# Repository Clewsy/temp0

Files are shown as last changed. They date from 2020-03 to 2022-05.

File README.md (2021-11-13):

# temp0
A temperature/humidity sensor that provides live readings over WiFi and via an oled display.
The device connects to a local network over WiFi and serves the following:
- Pretty html page at root:
	- http://temp0
- Simple text only temperature value at:
	- http://temp0/temperature
	- http://temp0/temp
	- http://temp0/t
- Simple text only humidity value at:
	- http://temp0/humidity
	- http://temp0/humi
	- http://temp0/h

The code was developed using the [PlatformIO][link_web_platformio] extension in [VSCode][link_web_vscode].  The hardware was designed using [KiCAD][link_web_kicad] and fabricated using [JLCPCB][link_web_jlcpcb].

All components are on a custom PCB and inside an enclosure with a transperant lid so as to show off the special-edition [HackADay 10-year anniversary Pro Trinket][link_web_hackaday_pro_trinket]!

More info can be found [here][link_clews_projects_temp0].

## Goals
This project was developed to meet a few goals:
- Create a device for monitoring internal temperature - to be compatible with automation platforms (specifically [Home Assistant][link_web_home_assistant]).
	- Local temperature read-out.
	- Simple web-server for obtaining temperature over WiFi.
	- Simple text-only response when calling a specific url with curl (also over WiFi). 
- Make use of - and potentially showcase - a special [HackADay 10-year anniversary edition Pro-Trinket][link_web_hackaday_pro_trinket] dev board.
- Learn how to use an [esp8266][link_web_esp8266].
- Try out [arduino][link_web_arduino] (instead of directly programming microcontrollers).
	- Try the [arduino IDE][link_web_arduino_ide] and programming via the arduino bootloader.
	- Try using some [C++][link_wiki_c++] for development instead of just [C][link_wiki_c].

## Components
The final system consists of the following components:
- [Pro Trinket 5V][link_repo_data_pro_trinket] (Hackaday 10-Year Anniversary Special-Edition) - Controls the SSD1306 and the HDC1080. Sends temperature/humidity readings over serial to the ESP8266 module.
- [ESP8266][link_repo_data_esp8266] (ESP-01 module) - Acts as a web-server to provide temperature/humidity over WiFi.
- [HDC1080][link_repo_data_hdc1080] module - Temperature/Humidity sensor that communicates over I2C.
- [SSD1306][link_repo_data_ssd1306] OLED module - also communicates over I2C - used as a local display for temperature/humidity readings.
- Miscellaneous components for power conversion (5V->3.3V), filtering, IO pull-ups, etc.

## Repository
This repo contains:
- [data][link_repo_temp0_data] - datasheets I referenced to write relevant code and create custom [KiCAD][link_web_kicad] footprints.
- [images][link_repo_temp0_images] - photos of the final project.
- [temp0_esp8266][link_repo_temp0_esp8266] - code written for the ESP8266/ESP-01 module.
- [temp0_pro_trinket][link_repo_temp0_pro_trinket] - code written for the Pro Trinket module.
- [temp0_schematic][link_repo_temp0_schematic] - [KiCAD][link_web_kicad] files including the schematic and PCB layout.  Library includes some custom parts (ESP-01, Pro-Trinket, HDC1080, OLED).
- [temp0_workspace.code-workspace][link_repo_temp0_workspace] - Workspace structure for VSCode including PlatformIO configurations for working with the ESP8266/ESP-01 and the Pro-Trinket 5V.

## Gallery
### Start-up animation.
Demo of startup

### Cycling through different display modes.
Demo of display modes

### Assembled PCB.
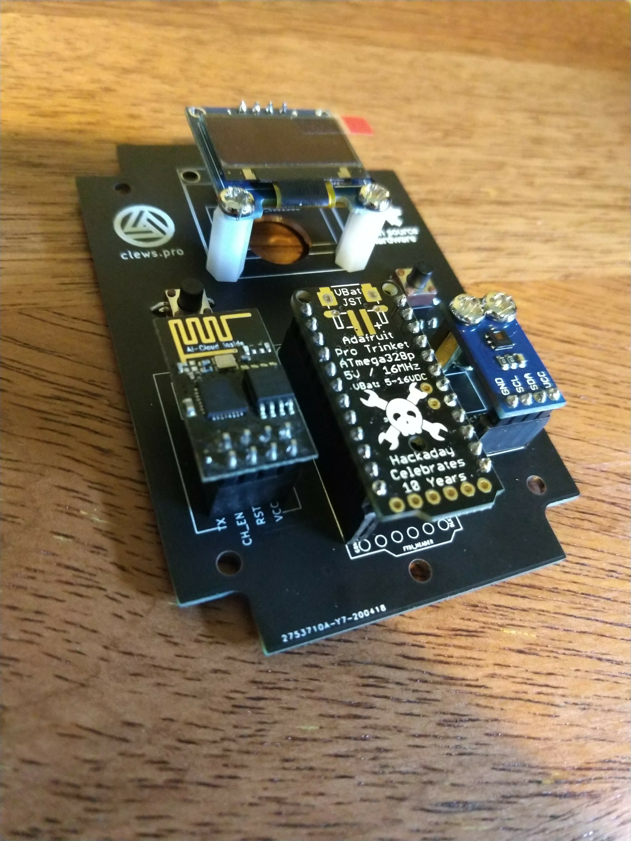
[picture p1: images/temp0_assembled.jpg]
Assembled unit


### In an enclosure.
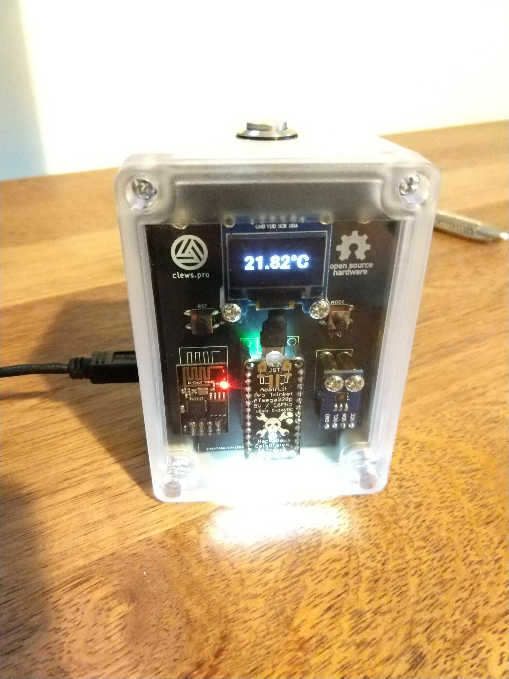
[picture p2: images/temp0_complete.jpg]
Buttoned up


### Web interface.
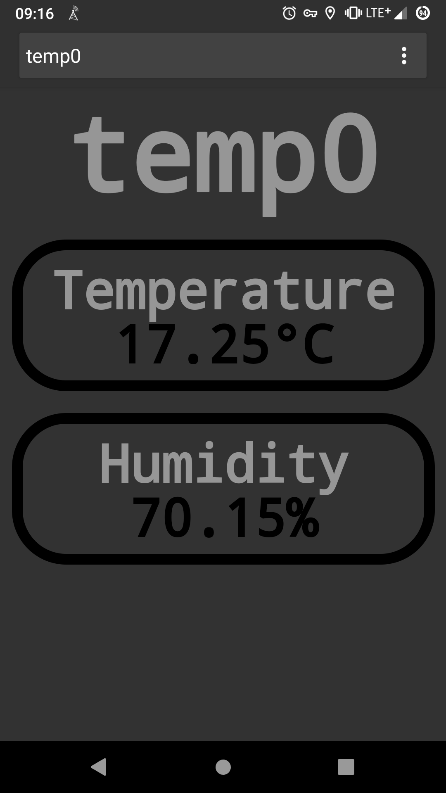
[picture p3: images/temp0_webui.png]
WebUI


[link_clews_projects_temp0]:https://clews.pro/projects/temp0.php

[link_repo_temp0_data]:/data
[link_repo_data_esp8266]:/data/esp8266_pinout.png
[link_repo_data_hdc1080]:/data/hdc1080_i2c_temperature_humidity_sensor.pdf
[link_repo_data_pro_trinket]:/data/pro_trinket_5V_pinout.jpeg
[link_repo_data_ssd1306]:/data/ssd1306_oled_driver.pdf

[link_repo_temp0_esp8266]:/temp0_esp8266
[link_repo_temp0_images]:/images
[link_repo_temp0_pro_trinket]:/temp0_pro_trinket
[link_repo_temp0_schematic]:/temp0_schematic
[link_repo_temp0_workspace]:/temp0_workspace.code-workspace

[link_web_arduino]:https://www.arduino.cc/
[link_web_arduino_ide]:https://www.arduino.cc/en/Main/Software
[link_web_esp8266]:http://esp8266.net/
[link_web_hackaday_pro_trinket]:https://hackaday.com/2014/10/10/10th-anniversary-trinket-pro-now-in-the-hackaday-store/
[link_web_home_assistant]:https://www.home-assistant.io/
[link_web_jlcpcb]:https://jlcpcb.com/
[link_web_kicad]:https://kicad.org/
[link_web_platformio]:https://platformio.org/
[link_web_vscode]:https://code.visualstudio.com/

[link_wiki_c]:https://en.wikipedia.org/wiki/C_(programming_language)
[link_wiki_c++]:https://en.wikipedia.org/wiki/C%2B%2B

[image_temp0_assembled]:/images/temp0_assembled.jpg
[image_temp0_complete]:/images/temp0_complete.jpg
[image_temp0_demo_modes]:/images/temp0_demo_modes.gif
[image_temp0_demo_startup]:/images/temp0_demo_startup.gif
[image_temp0_webui]:/images/temp0_webui.png

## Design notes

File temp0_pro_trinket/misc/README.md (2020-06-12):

# Embedded bitmaps

This directory contains the bitmap images embedded in the pro trinket for displaying on the oled.

The original bitmaps have the suffix *original*.

These original files were manipulated by reversing the order of each 8-bit pixel column, resulting in 8 "rows" flipped vertically.  This manipulation was done to suit an online bitmap-to-char-array convert I used to create the include/ssd1306_bitmaps.h header file which contains these arrays.

The online converter I used is [dot2pic.com][link_web_dot2pic].

Converting images this way allowed me to print them to the OLED with *map_bits* function using the same OLED addressing method as the *clear_screen* function.

[link_web_dot2pic]:http://dot2pic.com/

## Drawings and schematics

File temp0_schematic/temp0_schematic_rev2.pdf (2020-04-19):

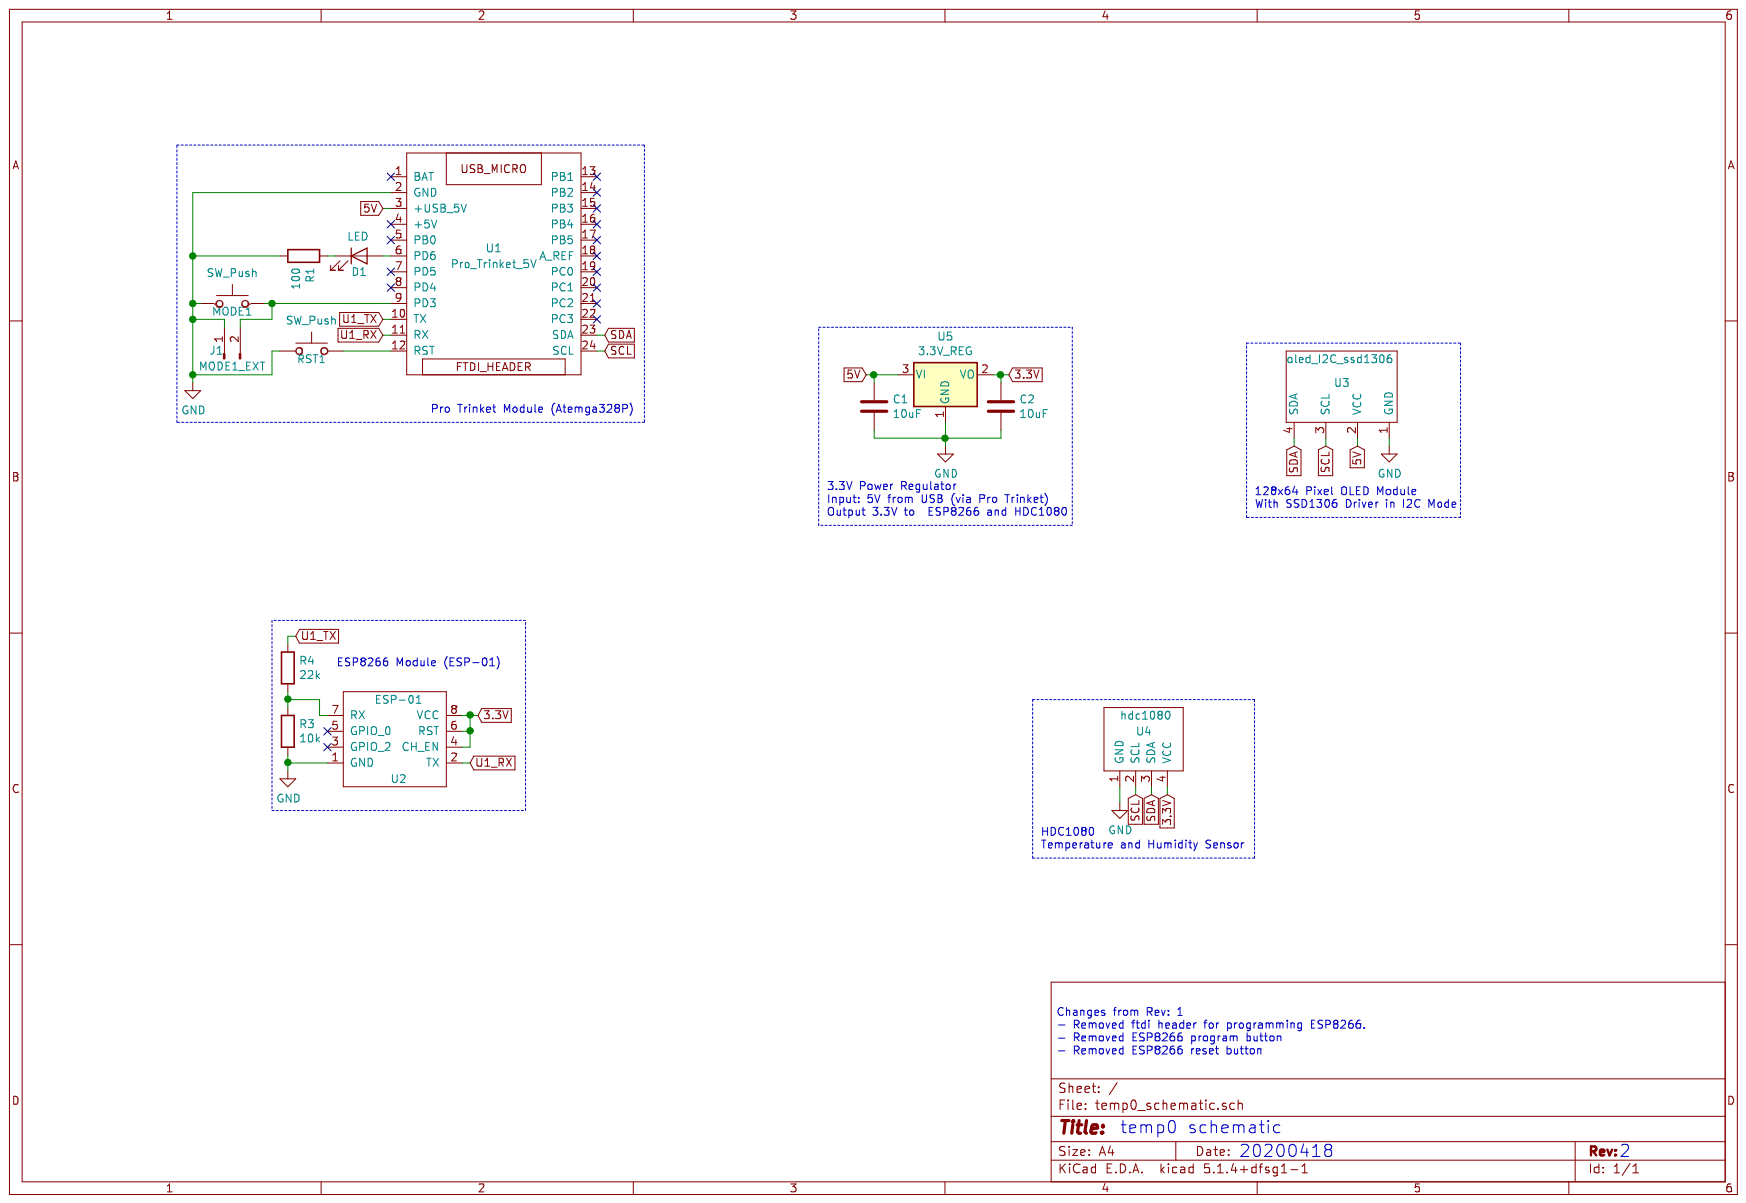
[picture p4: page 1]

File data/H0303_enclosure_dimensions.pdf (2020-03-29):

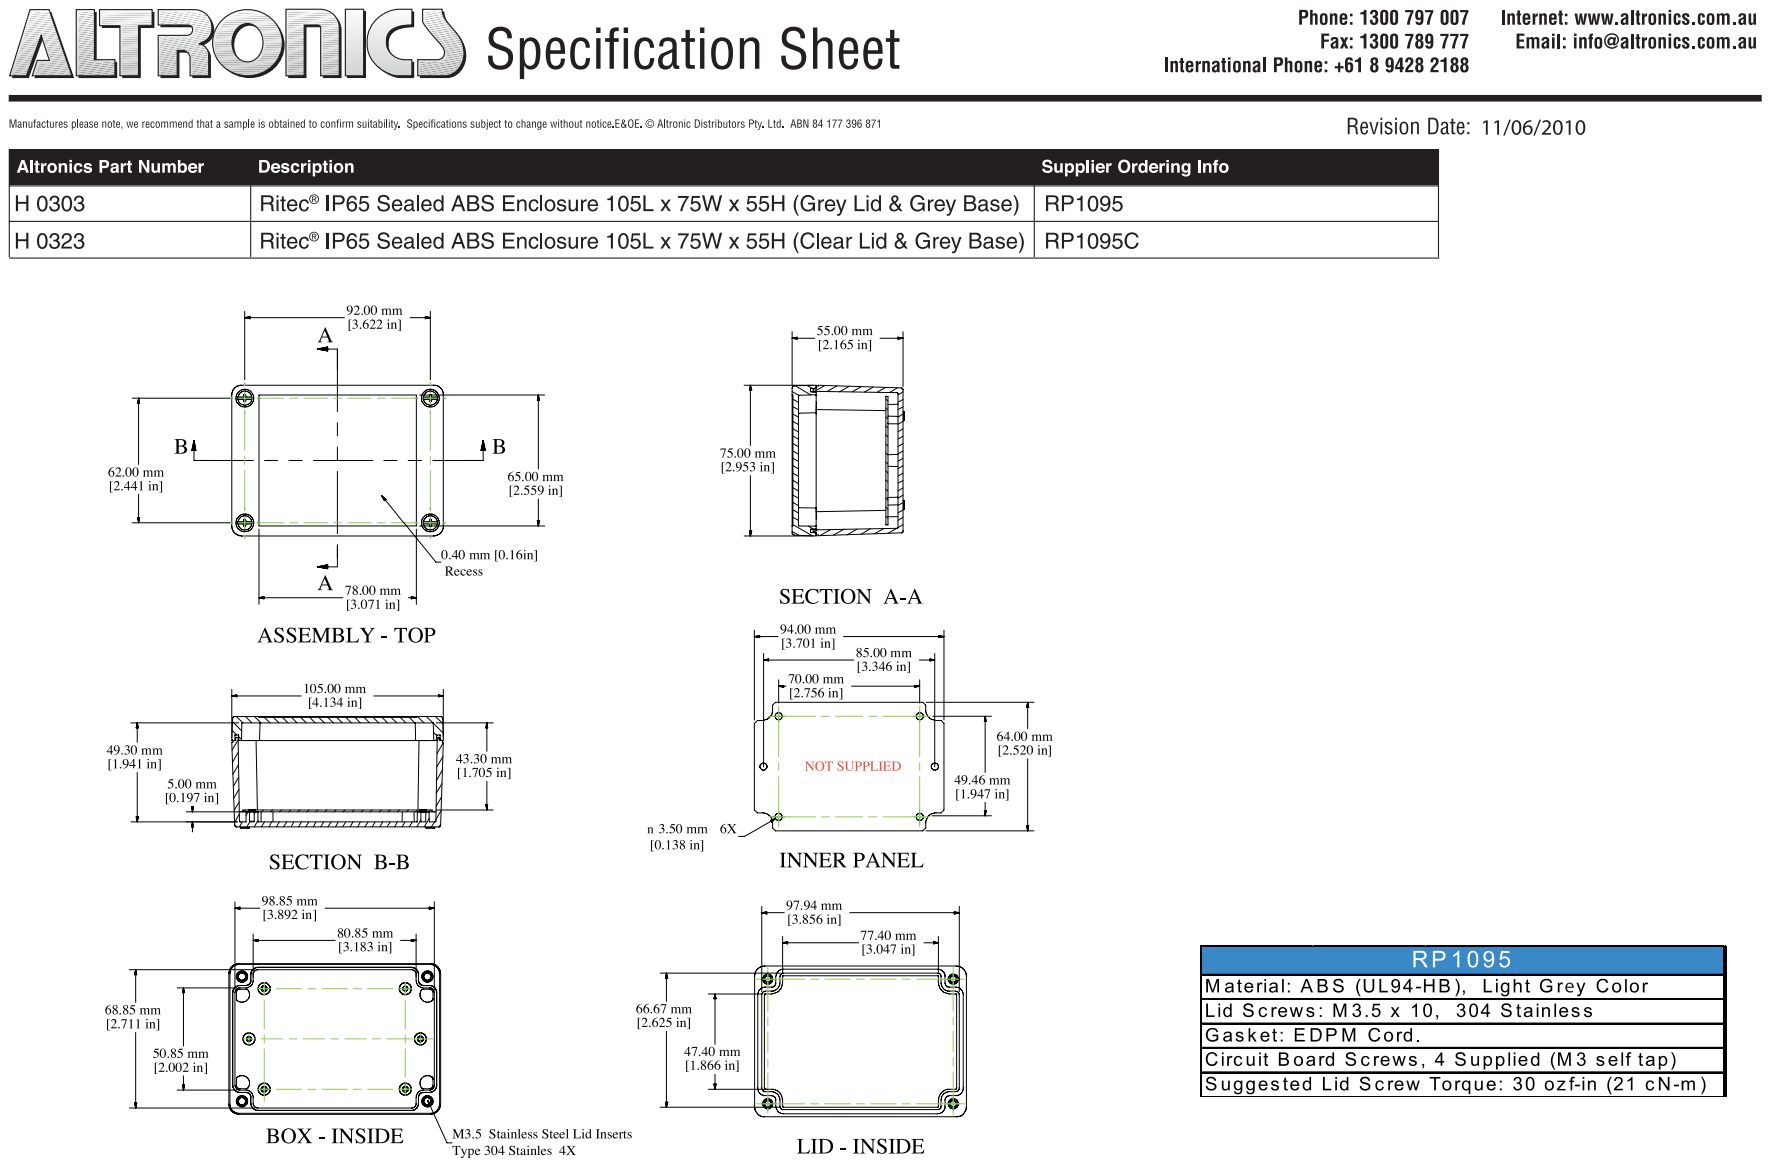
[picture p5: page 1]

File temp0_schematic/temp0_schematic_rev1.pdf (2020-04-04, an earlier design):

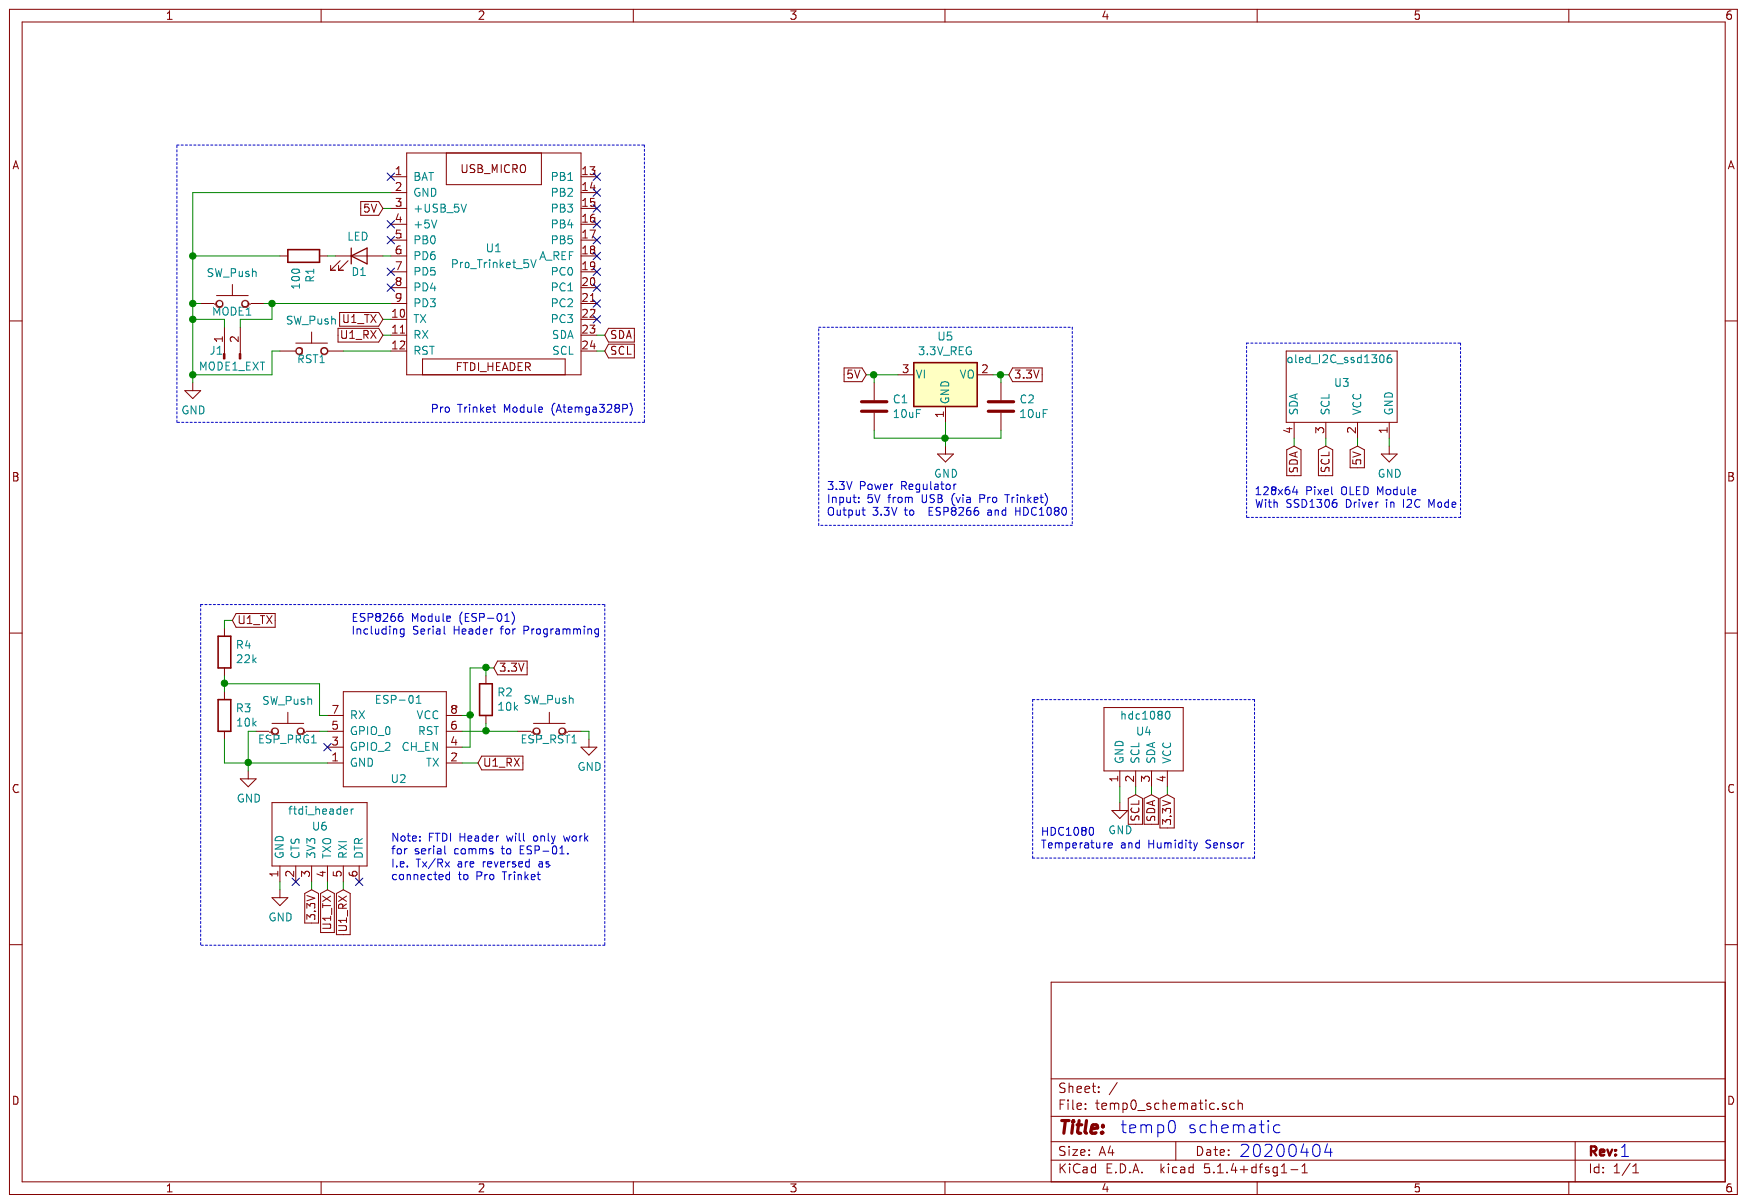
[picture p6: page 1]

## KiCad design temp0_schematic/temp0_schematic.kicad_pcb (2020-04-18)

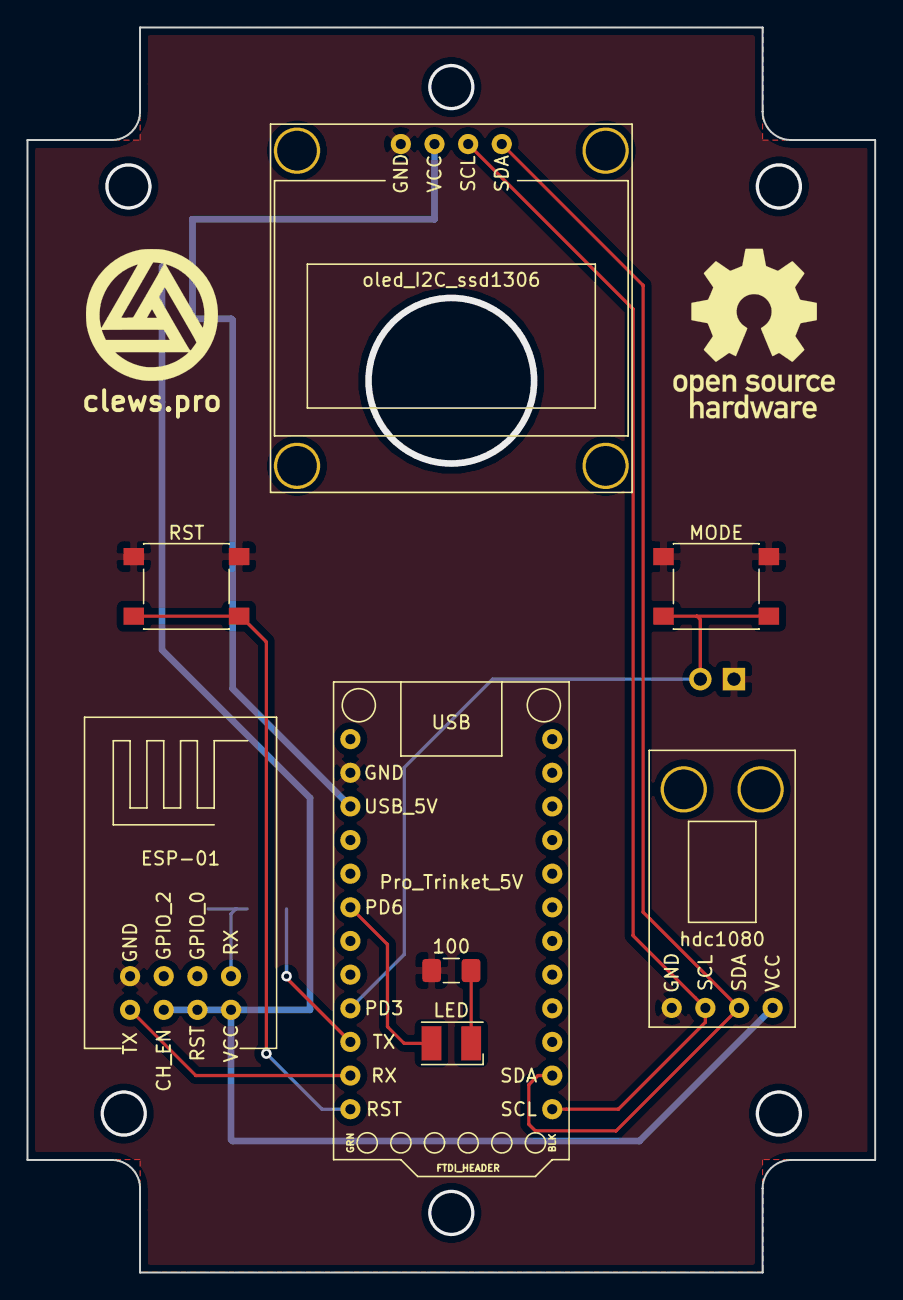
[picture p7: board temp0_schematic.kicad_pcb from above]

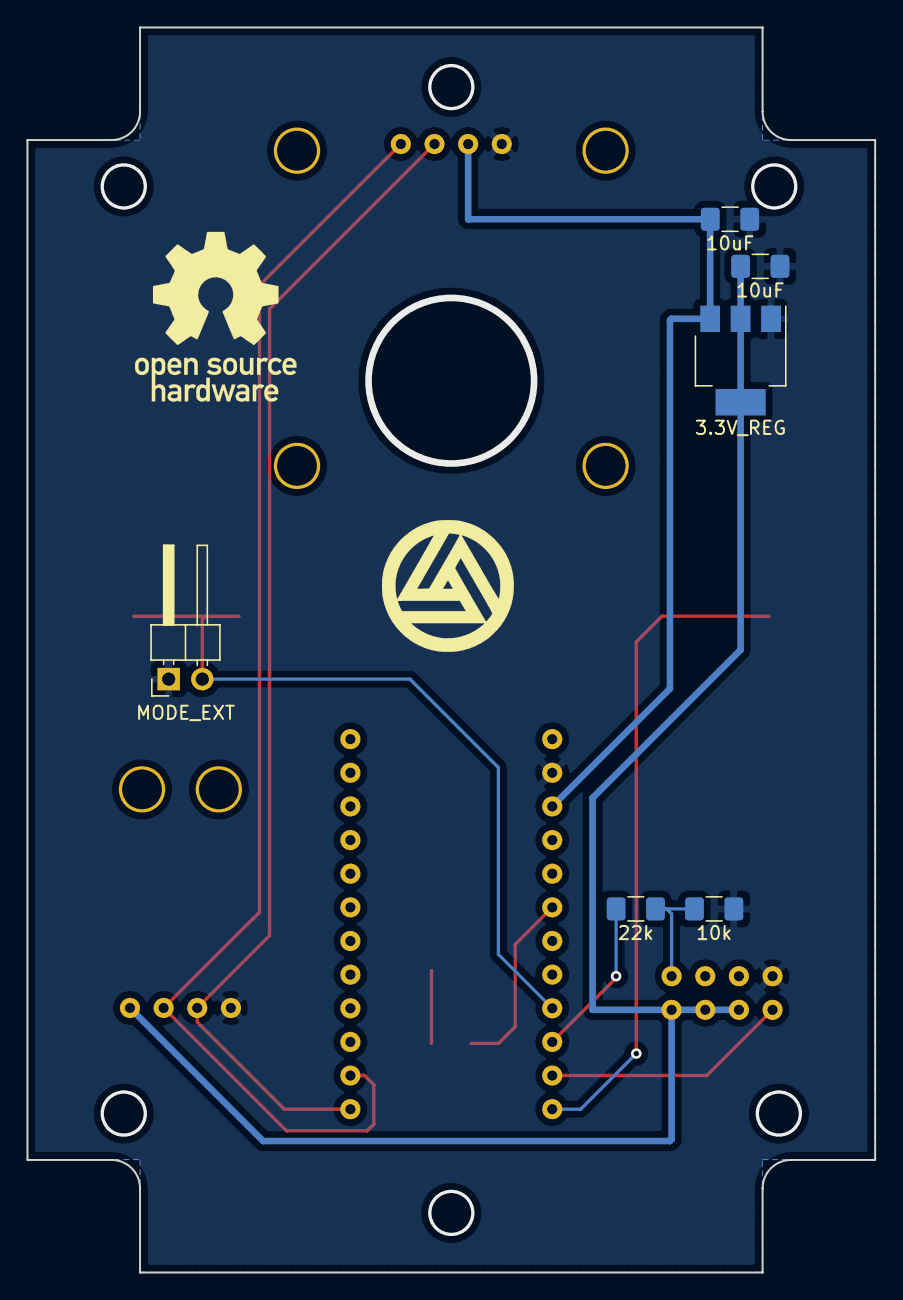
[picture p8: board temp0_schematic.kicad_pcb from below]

Board: 2 copper layers, 64.0 x 94.0 mm, 14 parts (6 on the bottom side), 12 nets.

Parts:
C1, C2: 10uF; C_1206_3216Metric_Pad1.42x1.75mm_HandSolder
D1: LED; LED_PLCC-2
J1: MODE_EXT; PinHeader_1x02_P2.54mm_Horizontal
MODE: SW_Push; SW_Push_1P1T_NO_6x6mm_H9.5mm
R1: 100; R_1206_3216Metric_Pad1.42x1.75mm_HandSolder
R3: 10k; R_1206_3216Metric_Pad1.42x1.75mm_HandSolder
R4: 22k; R_1206_3216Metric_Pad1.42x1.75mm_HandSolder
RST: SW_Push; SW_Push_1P1T_NO_6x6mm_H9.5mm
U1: Pro_Trinket_5V
U2: ESP-01
U3: oled_I2C_ssd1306; oled_i2c_ssd1306
U4: hdc1080
U5: 3.3V_REG; SOT-223-3_TabPin2

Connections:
3.3V: C2.1, U2.4, U2.6, U2.8, U4.4, U5.2
5V: C1.1, U1.3, U3.2, U5.3
GND: C1.2, C2.2, J1.1, MODE.1, R1.2, R3.2, RST.1, U1.2, U2.1, U3.1, U4.1, U5.1
unnamed: D1.1, R1.1
unnamed: D1.2, U1.6
unnamed: J1.2, MODE.2, U1.9
unnamed: R3.1, R4.2, U2.7
unnamed: RST.2, U1.12
SCL: U1.24, U3.3, U4.2
SDA: U1.23, U3.4, U4.3
U1_RX: U1.11, U2.2
U1_TX: R4.1, U1.10

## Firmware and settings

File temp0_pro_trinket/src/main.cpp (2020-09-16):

#include "temp0.h"

// Global variables.
hdc1080 sensor;		// Initialise an hdc1080 sensor called "sensor".  Refer "hdc1080.h".
ssd1306 display;	// Initialise an oled display with ssd1306 driver called "display".  Refer "ssd1306.h"


// Configure the timer interrupt (for LED pulsing).
void led_pulse_init(void)
{
	TCCR2B |= (1 << CS02) | (1 << CS01) | (1 << CS00);	// Set divisor to 1024.
								// Overflow frequency = 1 / ((1/F)(2^8)(divisor))
}								// With divisor set to 1024, overflow frequency ~ 61Hz.

// Enable (true) or disable (false) the pulsing LED.
void led_pulse(bool enable)
{
	analogWrite(LED_EXTERNAL, 0);			// If enabling or disabling the LED pulse, always set the analogue brightness value to zero.

	if(enable)	TIMSK2 |= (1 << TOIE2);		// Set Timer Overflow Interrupt Enable bit in the Timer 2 Interrupt Mask Register.
	else		TIMSK2 &= ~(1 << TOIE2);	// Clear Timer Overflow Interrupt Enable bit in the Timer 2 Interrupt Mask Register.
}

// Timer 2 interrupt subroutine vector.  Used to pulse the external LED.
ISR(TIMER2_OVF_vect)
{
	led_value = (led_value + (led_pulse_dir * LED_PULSE_SPEED));						// Increment or decrement led_value by LED_PULSE_SPEED.

	if((led_value > (LED_MAX_VALUE-LED_PULSE_SPEED)) | (led_value == 0)) led_pulse_dir = -led_pulse_dir;	// Reverse direction at either extreme of led_value.

	analogWrite(LED_EXTERNAL, led_value);									// Update the brightness of the external led.
}

// Interrupt sub-routine that is triggered by pressing the push-button.
void ISR_button(void)
{
	// Button debounce.
	if(((millis() - trigger_time) > BUTTON_DEBOUNCE) && (digitalRead(BUTTON_PIN)==LOW))
	{
		mode++;				// Increment to the next mode.
		if(mode > MODE_BLANK) mode = 0;	// Rollover from the last mode to the first.
		trigger_time = millis();	// Reset the button debounce timer.
	}
}

// Function to send temperature and humidity data as ascii strings to the ESP8266 over serial.
void send_data(double temp, double humi)
{
	// Send temperature string to esp8266.
	Serial.print("t");	// 't' indicates beginning of temperature string data.
	Serial.print(temp);	// Serial.print converts double to ascii string.
	Serial.print(";");	// ';' indicates end of data.

	// Send humidity string to esp8266.
	Serial.print("h");	// 'h' indicates beginning of humidity string data.
	Serial.print(humi);	// Serial.print converts double to ascii string.
	Serial.print(";");	// ';' indicates end of data.
}

// Function to update the oled display.
void update_oled (double temp, double humi)
{
	// Create an asci character string in the format - 12.34°C - to indicate current temperature.
	unsigned char temp_string[8];			// Define a character array that will be printed as a string to show temperature : ##.##°C
	dtostrf(temp, 5, 2, (char*)temp_string);	// Double-to-String function.  Syntax dtostrf(double, min_string_length, num_post_decimal_values, char_array_addr).
	temp_string[5] = 0xB0;				// Append '°' to the string after the actual value.
	temp_string[6] = 'C';				// Append 'C' (Celcius) to the string after the ° symbol.
	temp_string[7] = 0x00;				// Indicates end of character array.

	// Create an asci character string in the format - 56.78% - to indicate current humidity.
	unsigned char humi_string[7];			// Define a character array that will be printed as a string to show humidity : ##.##%
	dtostrf(humi, 5, 2, (char*)humi_string);	// Double-to-String function.  Syntax dtostrf(double, min_string_length, num_post_decimal_values, char_array_addr).
	humi_string[5] = '%';				// Append '%' to the string after the actual value.
	humi_string[6] = 0x00;				// Indicates end of character array.

	// Check if the display mode has changed.
	if(mode != last_mode)
	{
		display.map_bits(BLANK, sizeof(BLANK));		// Clear the screen.

		if(mode >= MODE_BLANK)	led_pulse(false);	// If changed to blank screen mode, disable LED pulse.
		else			led_pulse(true);	// Otherwise, enable LED pulse.

		last_mode = mode;				// Update last_mode for next comparison.
	}

	// Alternating display modes are inverted.
	display.invert_screen(mode & 1);	// I.e. Inverse enabled by lsb of mode byte.

	switch(mode)
	{
		case MODE_NORMAL:									// Normal modes:
		case MODE_NORMAL_INVERSE:								//  _______________
			display.print_string((unsigned char*)"Temperature", Roboto_Black_12, 0, 0);	// |Temperature    |
			display.print_string((unsigned char*)temp_string, Roboto_Black_12, 2, 0);	// |12.34°C        |
			display.print_string((unsigned char*)humi_string, Roboto_Black_12, 4, 87);	// |         56.78%|
			display.print_string((unsigned char*)"Humidity", Roboto_Black_12, 6, 80);	// |_______Humidity|
			break;

		case MODE_LARGE:									// Large modes:
		case MODE_LARGE_INVERSE:								//  _________
			display.print_string((unsigned char*)temp_string, Roboto_Black_26, 0, 16);	// | 12.34°C |
			display.print_string((unsigned char*)humi_string, Roboto_Black_26, 4, 20);	// |_56.78_%_|
			break;

		case MODE_TEMP_ONLY:									// Temp only modes:
		case MODE_TEMP_ONLY_INVERSE:								//  _________
			display.print_string((unsigned char*)temp_string, Roboto_Black_26, 2, 16);	// |         |
			break;										// | 12.34°C |
													// |_________|
		case MODE_BLANK:				// Blank screen.
			display.map_bits(BLANK, sizeof(BLANK));
	}
}

// Display start-up animation.
void splash_screen(void)
{
	display.map_bits(LOGO_CLEWS, sizeof(LOGO_CLEWS));
	delay(500);
	display.map_bits(LOGO_HAD, sizeof(LOGO_HAD));
	delay(500);
	display.map_bits(BLANK, sizeof(BLANK));
	display.draw_box(0, 0, 64, 128);
	display.print_string((unsigned char*)"temp0", Roboto_Black_12, 3, 45);
}

void setup(void)
{
	// Initialize output pins.
	pinMode(LED_BUILTIN, OUTPUT);	// LED_BUILTIN - used to indicate when the Pro Trinket is booting/ready.
	pinMode(LED_EXTERNAL, OUTPUT);	// External LED connected to a output pin.

	// Turn on built-in LED to indicate Pro Trinket is "booting".
	digitalWrite(LED_BUILTIN, HIGH);

	// Initialise UART at 115200baud.
	Serial.begin(115200);

	// Initialise I2C comms and set speed.
	Wire.begin();
	Wire.setClock(400000);	//Default is 100kHz but devices in this system are capable of 400kHz.

	// Initialise sensor using the hdc1080 header and functions.
	sensor.init();

	// Initialise oled using the ssd1306 header and functions.
	display.init();

	// Display start-up animation.
	splash_screen();

	// Run heater for 5 seconds while the splash screen is displayed.
	sensor.run_heater(5);
	display.map_bits(BLANK, sizeof(BLANK));

	// Initialise the timer/counter interrupt that will control the pulsing LED, then enable pulsing.
	led_pulse_init();
	led_pulse(true);

	// Turn off built-in LED to indicate Pro Trinket has finished "booting".
	digitalWrite(LED_BUILTIN, LOW);

	// After all other initialisations are complete, enable the push-button interrupt.
	pinMode(BUTTON_PIN, INPUT_PULLUP);
	attachInterrupt(digitalPinToInterrupt(BUTTON_PIN), ISR_button, LOW);
}

void loop(void)
{
	double *sensor_array = sensor.get_sensor_data();		// Update temperature and humidity readings.

	send_data(sensor_array[TEMPERATURE], sensor_array[HUMIDITY]);	// Send temperature and humidity readings to the esp8266 (converts double to string).

	update_oled(sensor_array[TEMPERATURE], sensor_array[HUMIDITY]);	// Update the oled display with the latest temperature and humidity readings.
}

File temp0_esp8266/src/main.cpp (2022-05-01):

#include "temp0.h"

// Initiate an esp8266 webserver called "server".
ESP8266WebServer server(80);

// Parse the temperature value (in plain text) from the serial string.
String get_temp()
{
	Serial.find('t');				// Character 't' indicates start of serial string with temperature value.
	String temp = Serial.readStringUntil(';');	// Character ';' indicates end of the temp string.
	if(temp == "")	temp = "error";			// Will print "error" if the esp8266 is not receiving the serial string.
	return temp;
}

// Parse the humidity value (in plain text) from the serial string.
String get_humi()
{
	Serial.find('h');				// Character 'h' indicates start of serial string with humidity value.
	String humi = Serial.readStringUntil(';');	// Character ';' indicates end of the humi string.
	if(humi == "")	humi = "error";			// Will print "error" if the esp8266 is not receiving the serial string.
	return humi;
}

// Just print in plain text the temperature value string (succeeded by a newline character).
void handle_temp() { server.send(200, "text/plain", (get_temp() + '\n')); }

// Just print in plain text the humidity value string (succeeded by a newline character).
void handle_humi() { server.send(200, "text/plain", (get_humi() + '\n')); }

// Print a pretty page showing temperature and humidity.  
// The large block is a base64 encoded png file to serve as a favicon.
void handle_root()
{
	String page = "<!DOCTYPE html>\n"; 
	page += "<html>\n";
	page += "<head>\n";
	page += "<link rel='icon' href='data:image/png;base64,";
	page += "iVBORw0KGgoAAAANSUhEUgAAAEAAAABACAYAAACqaXHeAAAABmJLR0QA/wD/AP+gvaeTAAACqklE";
	page += "QVR4nO2byW4TQRCGv3hJciACBDeWO1JuPAKJWAQigsADkCMJm1+AIwHlLUC8CViRgxMgGClckkhw";
	page += "BBFAYjMcqlpjWV5i1FOFrf6kVqtrqjV//Z7pGdszkEhYMwHcAqrAF21VYEm3jTTHgXXgT5e2rjkj";
	page += "ySSwgRS6A1wFprTNAW/JTBjJI+E2UmADONxh+yEyE5YMdZmxihR3uUfOFc2pmigyZg8pbqpHzkHN";
	page += "+WyiyJiw0MXKi0LBakf/K8kAbwHeJAO8BXjjacB5YFfbBUcdZrRf3nZbYjs98nJlzGpHZEWNtY3b";
	page += "tbTn5UpaA7wFeJMM8BbgTTLAW4A3yQBvAd4kA7wFeJMM8BbgTTLAW4A3yQBvAd4kA7wFeJMM8Bbg";
	page += "TTLAW4A3yQBvAd4kA7wFeJMMMNrP/X+Y8yC2CC9WkD88fwCVlnj7U6KBCvBTYytGGnPjHNBEip/R";
	page += "WAlY0HgovqmxkubMIiY0gbOGeqNSBraRAu9q7Cjwgu7PCq8BRzS3orFtMmOGiktIAVvIWlNCCuxW";
	page += "fGg1zS0A7zR20Vh7FJ4i4u/oeIH+xYd2Q+fc0/ETM9UReYmIP63jGvs3YFXnnNLxhpnqiHxCxIcn";
	page += "w7+xfwO+6pxJHX/MS2Se9wFF7X9p/3uAuWHOuPa56czTgPfan9D+zQBzQ+5J7T9EUdSBPA1Y035W";
	page += "+8cDzA2LXphbi6LImOvI+fsKOR0mgDr9z/86cugXgU2NzRtrj8I42XX8psaO0duEuuaAvFkW7iPK";
	page += "ZqojE16B+Q6c0dg4sAg8R94i2QOeaSwsejPI7XO/V2yGgkdkJiySXR06UUQ++VD8cu7qDCgAD8kO";
	page += "89fId4Np4IC2aeSub7Mlb5kR+71iDjmf+y2CW4zAYd+NMnANuSQ2yNaAhsbmGeIFLzGM/AVYSNm1";
	page += "OH1mOwAAAABJRU5ErkJggg==' ";
	page += "type='image/x-png' />\n";
	page += "<title>temp0</title>\n";
	page += "<style>\n";
	page += "	body {\n";
	page += "		background-color: rgb(50,50,50);\n";
	page += "		font-family: monospace;\n";
	page += "		text-align: center;\n";
	page += "		color: rgb(150,150,150);\n";
	page += "		font-weight: bold; }\n";
	page += "	h1 {\n";
	page += "		font-size: 96px;\n";
	page += "		margin: 0px 0px 0px 0px;}\n";
	page += "	h2 {\n";
	page += "		font-size: 48px;\n";
	page += "		margin: 0px 0px 0px 0px;\n";
	page += "		height: 50px;}\n";
	page += "	h3 {\n";
	page += "			font-size: 48px;\n";
	page += "		height: 50px;\n";
	page += "		margin: 0px 0px 0px 0px;\n";
	page += "		color: black;}\n";
	page += "	div.header {\n";
	page += "		margin: 0px;}\n";
	page += "	div.sensor {\n";
	page += "		text-align: center;\n";
	page += "		margin: 20px auto auto auto;\n";
	page += "		padding: 10px;\n";
	page += "		border-color: black;\n";
	page += "		border-style: solid;\n";
	page += "		border-radius: 50px;\n";
	page += "		border-width: 10px;\n";
	page += "		width: 350px;}\n";
	page += "</style>\n";
	page += "</head>\n";
	page += "<body>\n";
	page += "	<div class=\"header\">\n";
	page += "		<h1>temp0</h1>\n";
	page += "	</div>\n";
	page += "	<div class=\"sensor\">\n";
	page += "		<h2>Temperature</h2>\n";
	page += "		<h3>" + get_temp() + "&deg;C</h3>\n";
	page += "	</div>\n";
	page += "	<div class=\"sensor\">\n";
	page += "		<h2>Humidity</h2>\n";
	page += "		<h3>" + get_humi() + "%</h3>\n";
	page += "	</div>\n";
	page += "</body>\n";
	page += "</html>\n";

	server.send(200, "text/html", page);
}

// Basic default page output.
void handle_not_found()
{
	String message = "jolly roger sends his regards\n\n";
	message += "URI: ";
	message += server.uri();
	message += "\nMethod: ";
	message += (server.method() == HTTP_GET) ? "GET" : "POST";
	message += "\nArguments: ";
	message += server.args();
	message += "\n";
	for (uint8_t i = 0; i < server.args(); i++)
	{
		message += " " + server.argName(i) + ": " + server.arg(i) + "\n";
	}
	server.send(404, "text/plain", message);
}

// System initialisation.
void setup(void)
{
	// Initialise uart.
	Serial.begin(115200);

	// Initialise wifi station.
	WiFi.hostname(HOSTNAME);
	WiFi.begin(STASSID, STAPSK);

	// Wait for connection
	while (WiFi.status() != WL_CONNECTED) delay(500);

	// Define functions to call depending on full url address.
	server.on("/", handle_root);

	server.on("/t", handle_temp);
	server.on("/temp", handle_temp);
	server.on("/temperature", handle_temp);

	server.on("/h", handle_humi);
	server.on("/humi", handle_humi);
	server.on("/humidity", handle_humi);

	server.onNotFound(handle_not_found);

	// Initialise wifi web server.
	server.begin();
}

void loop(void)
{
	server.handleClient();
	MDNS.update();
}

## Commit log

2020-03-08 It's working! Temperature and humidity webserver.
2020-03-21 Working on oled ssd1306 driver and kicad schematic.
    [temp0.kicad_pcb, temp0.sch]
2020-03-22 Improved hdc1080 driver and implemented self-heat capability.
2020-03-22 Improvements, can print to oled now.
2020-03-22 Use splash screen duration to run heater. Remove unused fonts.
2020-03-24 Implemented a push-button with de-bounce on a hardware interrupt - will eventually control display modes.
2020-03-28 Broke functions out of main. Added output LED.
    [main.cpp, temp0.h]
2020-03-29 Working on the schematic and pcb (KiCad).
    [temp0.kicad_pcb, temp0.sch, temp0_schematic.kicad_pcb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]
2020-03-29 Working on the schematic. Added header for external button.
    [temp0_schematic.kicad_pcb, temp0_schematic.sch]
2020-03-30 Ran traces.
    [temp0_schematic.kicad_pcb]
2020-03-30 Completed first attempt at pcb. Generated gerbers to order fab.
    [temp0_schematic-B_Cu.gbr, temp0_schematic-B_Mask.gbr, temp0_schematic-B_SilkS.gbr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]
2020-03-31 PCB fixed - mount hole alignment, ftdi clearance, other.
    [temp0_schematic-B_Cu.gbr, temp0_schematic-B_Mask.gbr, temp0_schematic-B_SilkS.gbr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]
2020-04-03 Fixed oled initialisation - now enables internal regulator.
2020-04-04 Tidied schematic and added pdf to repo.
    [temp0_schematic.kicad_pcb, temp0_schematic.sch]
2020-04-04 Increased i2c speed.
2020-04-05 Added inverted oled display modes. Added external led pulse.
    [main.cpp, temp0.h]
2020-04-06 Improvements to character printing.
2020-04-06 Fixed LED puls (internal timer with overflo interrupt) centered large font display mode.
    [main.cpp, temp0.h]
2020-04-11 Improved string printing. Improved fonts. Added additional display modes.
2020-04-11 Edited comments. Changed interrupt init order.
2020-04-12 Tweaks to box drawing. Added sensor read delay back in.
2020-04-18 Flipped oled display for installation on PCB rev2.
2020-04-18 Schematic and PCB revision 2.
    [temp0_schematic-B_Cu.gbr, temp0_schematic-B_Mask.gbr, temp0_schematic-B_SilkS.gbr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]
2020-04-19 Merged reset function into init function.
    [hdc1080.cpp, hdc1080.h, main.cpp]
2020-04-19 Added rev2 schematic pdf.
2020-05-02 Improved LED pulse function.
2020-05-02 Added blank screen mode, added function to enable/disable pulsing LED.
2020-05-03 Added temperature bodge, updated readme, added photos.
    [hdc1080.cpp, hdc1080.h, main.cpp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]
2020-05-30 Dimmed pulse LED. Changed display mode ordering.
2021-11-10 Update README.md https://forum.kicad.info/t/warning-avoid-all-links-to-kicad-pcb-org-use-kicad-org/31521
